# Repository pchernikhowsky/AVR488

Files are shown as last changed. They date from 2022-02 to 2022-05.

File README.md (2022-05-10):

# AVR488

A [Prologix](http://prologix.biz)<sup>TM</sup> compatible<sub><sup>(ish)</sup></sub> USB to [IEEE 488/GPIB/HP-IB](https://en.wikipedia.org/wiki/IEEE-488) controller interface based on the ATmega168/328 microcontroller.
<p align="center">
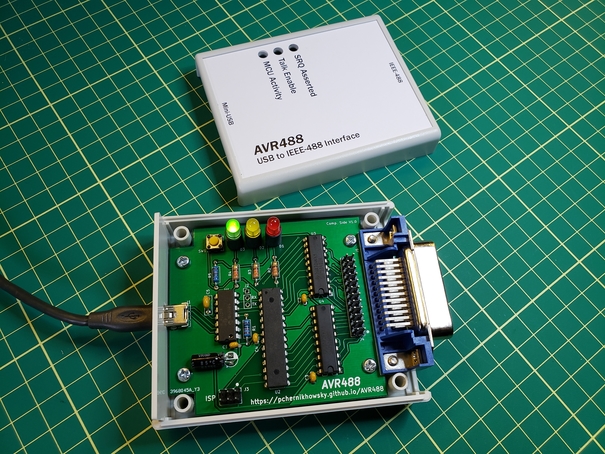
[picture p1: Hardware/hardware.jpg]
Completed hardware
  
</p>

## Description

I designed the AVR488 interface so that I could communicate with my various legacy Hewlett Packard / Agilent test instruments. There are numerous Arduino-based variations of USB/IEEE 488 interfaces out there already, but I prefer programming AVR devices down at the "bare metal" level using C code, so I came up with this version. Since it's necessary to construct a physical interface for the IEEE 488 connector anyway, it's easy enough to add an ATmega and driver ICs into that hardware design. Although it is intended to support a USB interface, a serial EIA-232 connection could also be implemented by deleting the USB interface IC and replacing it with an appropriate TTL to EIA-232 driver.

The embedded code size is approximately 13.5 KB and uses about 360 bytes of RAM, so there's more than enough free memory in an ATmega168 device. I have not included a bootloader (it avoids annoying startup delays and I prefer programming the ATmega directly using an ISP interface). If desired, there are many bootloaders available that could first be flashed to the device and then used to upload the AVR488 firmware.

**NOTE**: only controller mode (`++mode 1`) is implemented at this time, as I had no need for device mode. The latter is a possible future enhancement.

## Getting Started

### Dependencies

AVR488 supports both ATmega168 or ATmega328 devices (both the 10 and 20 MHz variants).

* Requires [MicroChip Studio 7 for AVR devices](https://www.microchip.com/en-us/tools-resources/develop/microchip-studio) for building the firmware.
* An ISP programmer (AVRISP MKII, AVR JTAG ICE, etc.) is needed to program the flash memory and set the fuses.

### Hardware Interfaces
* A USB 2.0 interface is provided by an [MCP2221A](https://www.microchip.com/en-us/product/MCP2221A) USB to TTL IC for connection to a host device (computer).
* The fully level-compliant IEEE 488 interface is implemented using the [SN75160](https://www.ti.com/lit/gpn/sn75als160) and [SN75161](https://www.ti.com/lit/gpn/sn75als161) driver ICs for connection to IEEE 488 devices.
* A direct serial EIA-232 interface could be implemented by using a [MAX232](https://www.ti.com/product/MAX232) (or equivalent) IC.

### Building and Installing the Firmware

1. Create a new project in MicroChip Studio and select the appropriate ATmega device.
2. Add the *.c and *.h files to the project.
3. Build the solution in MicroChip Studio.
4. Burn the code to your ATmega device.
5. Set the correct [fuses](Hardware/fuses.png):
   - Enable 8 MHz internal RC oscillator.
   - Disable divide by 8 clock divider (CKDIV8).
   - Enable brown-out detection (to provide protection against EEPROM corruption).
7. Connect the USB interface to a host computer and the IEEE 488 port to a device/instrument.
8. Upon first power-up, default settings will be stored in EEPROM. Settings can be changed and saved to EEPROM as required.
9. Enjoy!

When the AVR488 is first connected to a computer it will create a new USB serial port. The internal baud rate for the AVR488 serial port is fixed at 38400 bps (this can only be altered by changing a #define in the source code and reflashing). Thus, you MUST set the baud rate in your PC software (terminal program, etc.) to 38400 bps. A simple test to confirm that communications is fully working is to type the command "++help" (without the quotes). This should return a list available commands.

## Hardware Construction and Setup

You will need to construct your own hardware to support various ICs (ATmega168/328, MCP2221A, and SN75160/161) and the appropriate USB and IEEE 488 interface connectors. To make it easier, a full hardware design including [schematic](Hardware/AVR488-schematic.pdf), [bill of materials](Hardware/AVR488-BOM.csv), and PCB layout in KiCad format are provided. The PCB hardware and components have been selected to be hacker/hobbyist friendly; through-hole components are used exclusively. I ordered my PCBs from [JLCPCB](https://jlcpcb.com/), but feel free to use your preferred vendor. The PCB has been designed to fit inside a [Hammond 1593BB](https://www.hammfg.com/electronics/small-case/plastic/1593.pdf) plastic enclosure. A [dimensioned label](Hardware/AVR488-label.pdf) (including LED drilling dimensions) is also provided.

For simplicity, and to save pins, the internal 8 MHz RC oscillator in the ATmega168/328 is used as the clock source, so no external oscillator or crystal is required.

For diagnostic purposes, three LED outputs are provided:
* TE (Talk Enable): flashes when the TE signal to the IEEE 488 drivers goes high for driving data onto the bus.
* SRQ (Service Request): lights when the SRQ line is asserted, indicating that a device requires polling for status.
* STATUS: flashes during startup and then is continuously toggled when the watchdog timer is reset to indicate active processing (the toggling is around 130 kHz, so the LED is slightly dimmer than when fully on).

## Command List

The AVR488 command set is intended to be mostly compatible with the [Prologix GPIB-USB (HPIB-USB Controller)](http://prologix.biz/gpib-usb-controller.html). All commands are preceded by two plus signs (++). Any input not preceded by ++ is passed directly to the connected device(s). Input and commands from the host are buffered in a 254 byte buffer and then transmitted when either a CR (carriage return) or LF (line feed) character is received from the host. Not all Prologix commands have been implemented, and some do not operate exactly the same as the Prologix interface. Also, some extensions have been added for troubleshooting purposes (e.g., `debug` and `xdiag`) or for ease of use (e.g., `echo`).

Values enclosed in `[]` are optional. If a value is provided, the `[]` should not be included.

#### `++addr [n]`
Tell the interface which device to address (must be between 1 and 30). If no address is specified, the current device address will be displayed.

#### `++auto [n]`
Enable (1) or disable (0) automatic read-after-write when a "?" is included in the command sent to the device. If no value is provided, the current auto setting will be displayed.

#### `++clr`
Send a Select Device Clear (SDC) command to the currently addressed device.

#### `++debug [n]`
Enable simple (1), more verbose (2), or disable (0) debug logging messages. Convenient for troubleshooting problematic connections. If no value is provided, the current debug setting will be displayed.

#### `++default`
Emulates functionality of the AR488 command with the same name. The interface configuration is set with the following parameters:
* auto:	0
* eoi:	0 (disabled)
* eos:	0 (CR+LF)
* eot_enable:	0 (disabled)
* eot_char:	0
* address: 0
* read_tmo_ms:	1200
* echo: 0
* debug: 0

#### `++echo [n]`
Enable (1) or disable (0) echoing of characters received from USB port. Most IEEE 488 adapters require the sending application to enable local echo, but this is provided as an alternative. If no value is provided, the current echo setting will be displayed.

#### `++eoi [n]`
Enable (1) or disable (0) asserting the EOI line when the last byte is sent. If no value is provided, the current eoi setting will be displayed.

#### `++eos [n]`
Select the terminator characters to be appended to messages sent to the device: 0=CR+LF, 1=CR, 2=LF, 3=None. If no value is provided, the current eos setting will be displayed.

#### `++eot_char [n]`
ASCII code of character to be appended to messages received from the device (when EOI is used). If no value is provided, the current eot_char setting will be displayed.

#### `++eot_enable [n]`
Controls whether the eot_char is apprended to received messages. If no value is provided, the current eot_enable setting will be displayed.

#### `++help`
Print a list of commands and explanations.

#### `++ifc`
Issue an IEEE 488 interface clear by asserting the IFC line for 150 microseconds.

#### `++llo`
Disable front panel operation of the currently addressed device by sending the Local Lockout (LLO) command.

#### `++loc`
Enable front panel operation of the currently addressed device by sending the Go To Local (GTL) command.

#### `++mode [n]`
Compatibility-only command - we are always a controller. Any value provided is ignored and queries always return mode 1.

#### `++read`
Read from the currently addressed device until the eos terminating characters are received or a timeout occurs.

#### `++read eoi`
Read from the currently addressed device until either EOI is asserted, the eos terminating characters are received, or a timeout occurs.

#### `++read_tmo_ms [n]`
Sets the timeout value, in milliseconds, for the read and spoll commands. The default timeout is 1000 ms. If no value is provided, the current read_tmo_ms setting will be displayed.

#### `++rst`
Performs a power-on reset of the controller interface by forcing a watchdog timer timeout. Takes approximately 2 seconds.

#### `++savecfg 1`
Saves the current settings to EEPROM. Settings saved include: addr, eot_char, eot_enable, eos, eoi, auto, debug, and echo. Settings are **not** saved automatically when they are changed (to prevent unnecessary wear on the EEPROM). The value "1" must be included or the command is ignored.

#### `++spoll [n]`
Read the device status byte by issuing a Serial Poll command. If no address is specified the serial poll request will be sent to the currently addressed device.

#### `++srq`
Query the status of SRQ line. Returns 0 if the line is not asserted and 1 if asserted.

#### `++trg [n]`
Issue a Group Execute Trigger (GET) to a device. If no address is specified the trigger will be sent to the currently addressed device.

#### `++ver`
Query the current AVR488 firmware version.

#### `++xdiag`
Show the current state of the ATmega IO pins (for troubleshooting purposes).

## Version History

* 1.1
    * Firmware changes to improve AR488 and Prologix compatibility.
* 1.0
    * Initial Release

## License

This project is licensed under the GPL-3.0 License. See the [LICENSE](LICENSE) file for details.

## Acknowledgments

Inspiration, code snippets, libraries.
* [AR488](https://github.com/Twilight-Logic/AR488)
* [atmega-gpib](https://github.com/pepaslabs/atmega-gpib)
* [gpibusb-firmware](https://github.com/Galvant/gpibusb-firmware)
* [Peter Fleury's interrupt-driven UART library](http://www.peterfleury.epizy.com/doxygen/avr-gcc-libraries/group__pfleury__uart.html)

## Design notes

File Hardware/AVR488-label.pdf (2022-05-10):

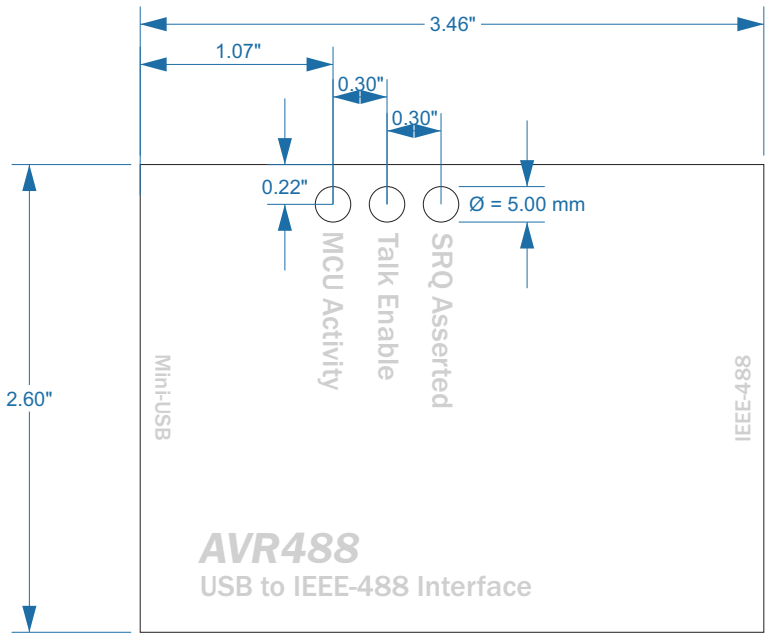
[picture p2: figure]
AVR488; USB to IEEE-488 Interface MCU Activity Talk Enable; SRQ Asserted; IEEE-488; Mini-USB

## AVR488

USB to IEEE-488 Interface MCU Activity Talk Enable

SRQ Asserted

IEEE-488

Mini-USB

Dimensioned for Hammond 1593BB enclosure http://www.hammondmfg.com/pdf/1593BB.pdf

Ensure “Actual size” is selected in the Print dialog.

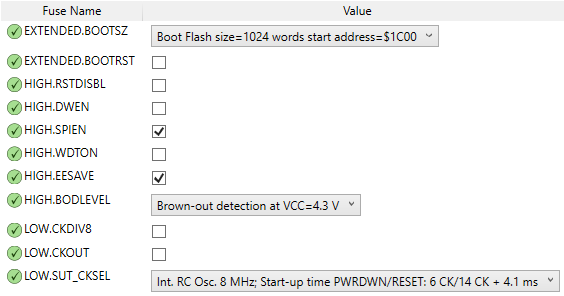
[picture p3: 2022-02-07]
Hardware/fuses.png

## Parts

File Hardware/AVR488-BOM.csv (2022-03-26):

Qty | Reference(s) | Value | Manufacturer | Digi-Key Part Number | PartNo
4 | C1, C2, C3, C4 | 0.1uF | KEMET | 399-4264-ND | C320C104K5R5TA
1 | C5 | 0.47 uF | KEMET | 399-14020-ND | C330C474M5R5TA
1 | C6 | 1uF | Nichicon | 493-12567-1-ND | UVK1H010MDD1TD
1 | D1 | LED(R) | Lite-On | 160-1705-ND | LTL-307E
1 | D2 | LED(Y) | Lite-On | 160-1703-ND | LTL-307Y
1 | D3 | LED(G) | Lite-On | 160-1706-ND | LTL-307G
1 | J1 | Mini USB | TE Connectivity AMP Connectors | A135698-ND | 2172034-1
1 | J2 | SERIAL | Amphenol ICC (FCI) | 10129378-903001BLF-ND | 10129378-903001BLF
1 | J3 | ISP | Amphenol ICC (FCI) | 10129381-906001BLF-ND | 10129381-906001BLF
1 | J4 | HEADER | Amphenol ICC (FCI) | 10129381-924001BLF-ND | 10129381-924001BLF
1 | J5 | IEEE488 | NorComp Inc. | 1024RMA-ND | 112-024-113R001
2 | R1, R5 | 10k | Stackpole Electronics Inc | CF18JT10K0TR-ND | CF18JT10K0
3 | R2, R3, R4 | 330R | Stackpole Electronics Inc | CF18JT330RTR-ND | CF18JT330R
1 | SW1 | RESET | Omron | SW797CT-ND | B3F-6002
1 | U1 | MCP2221AxP | Microchip Technology | MCP2221A-I/P-ND | MCP2221A-I/P
1 | U2 | ATmega168-20P | Microchip Technology | ATMEGA168V-10PU-ND | ATMEGA168V-10PU
1 | U3 | SN75161BN | Texas Instruments | 296-6847-5-ND | SN75161BN
1 | U4 | SN75160BN | Texas Instruments | 296-6845-5-ND | SN75160BN
3 |  | LED Standoffs | Bivar Inc. | ELM3-440-ND | ELM 3-440
2 |  | #4-40 connector mounting screws | Keystone | 36-9900-ND | 9900
1 |  | Enclosure | Hammond Manufacturing | HM1376-ND | 1593BBGY

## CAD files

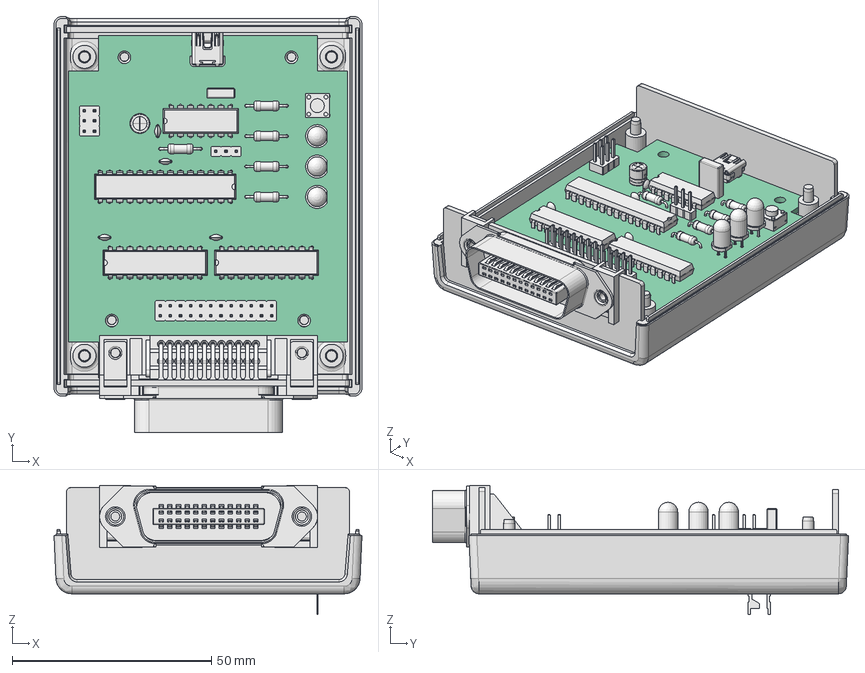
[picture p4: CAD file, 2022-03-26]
Hardware/AVR488.FCStd
77.3 x 104.4 x 32.4 mm
1593BB BOTTOM
1593BB End Panel
1593BB End Panel001
SC549 (screw #4X 3_4' OH)
SC549 (screw #4X 3_4' OH)001
SC549 (screw #4X 3_4' OH)002
SC549 (screw #4X 3_4' OH)003
Pcb_4d56
U1_DIP-14_W7.62mm_07c7e3d0463e
R3_R_Axial_DIN0207_L63mm_D25mm_P1016mm_Horizontal_f71aacabab9c x 5
U4_DIP-20_W7.62mm_8dba236a9cba x 2
D2_LED_D5.0mm_e4c8e7621137 x 3
J4_PinHeader_2x12_P254mm_Vertical_2a5a55a7fb98
J3_PinHeader_2x03_P254mm_Vertical_44d44c696a08
U2_DIP-28_W7.62mm_c51a3d9690d5
C4_C_Disc_D30mm_W16mm_P250mm_9aaeda4f0cdd x 4
J2_PinHeader_1x03_P254mm_Vertical_70d33e2d6c7e
C5_C_Rect_L70mm_W25mm_P500mm_720b4647ee08
C6_CP_Radial_D50mm_P250mm_bbad7ffecfd3
J5_112-024-113R001_fb36ff756c3c
SW1_B3F_602[]_423e57562a1d
J1_C-2172034-1_a05471a474e2

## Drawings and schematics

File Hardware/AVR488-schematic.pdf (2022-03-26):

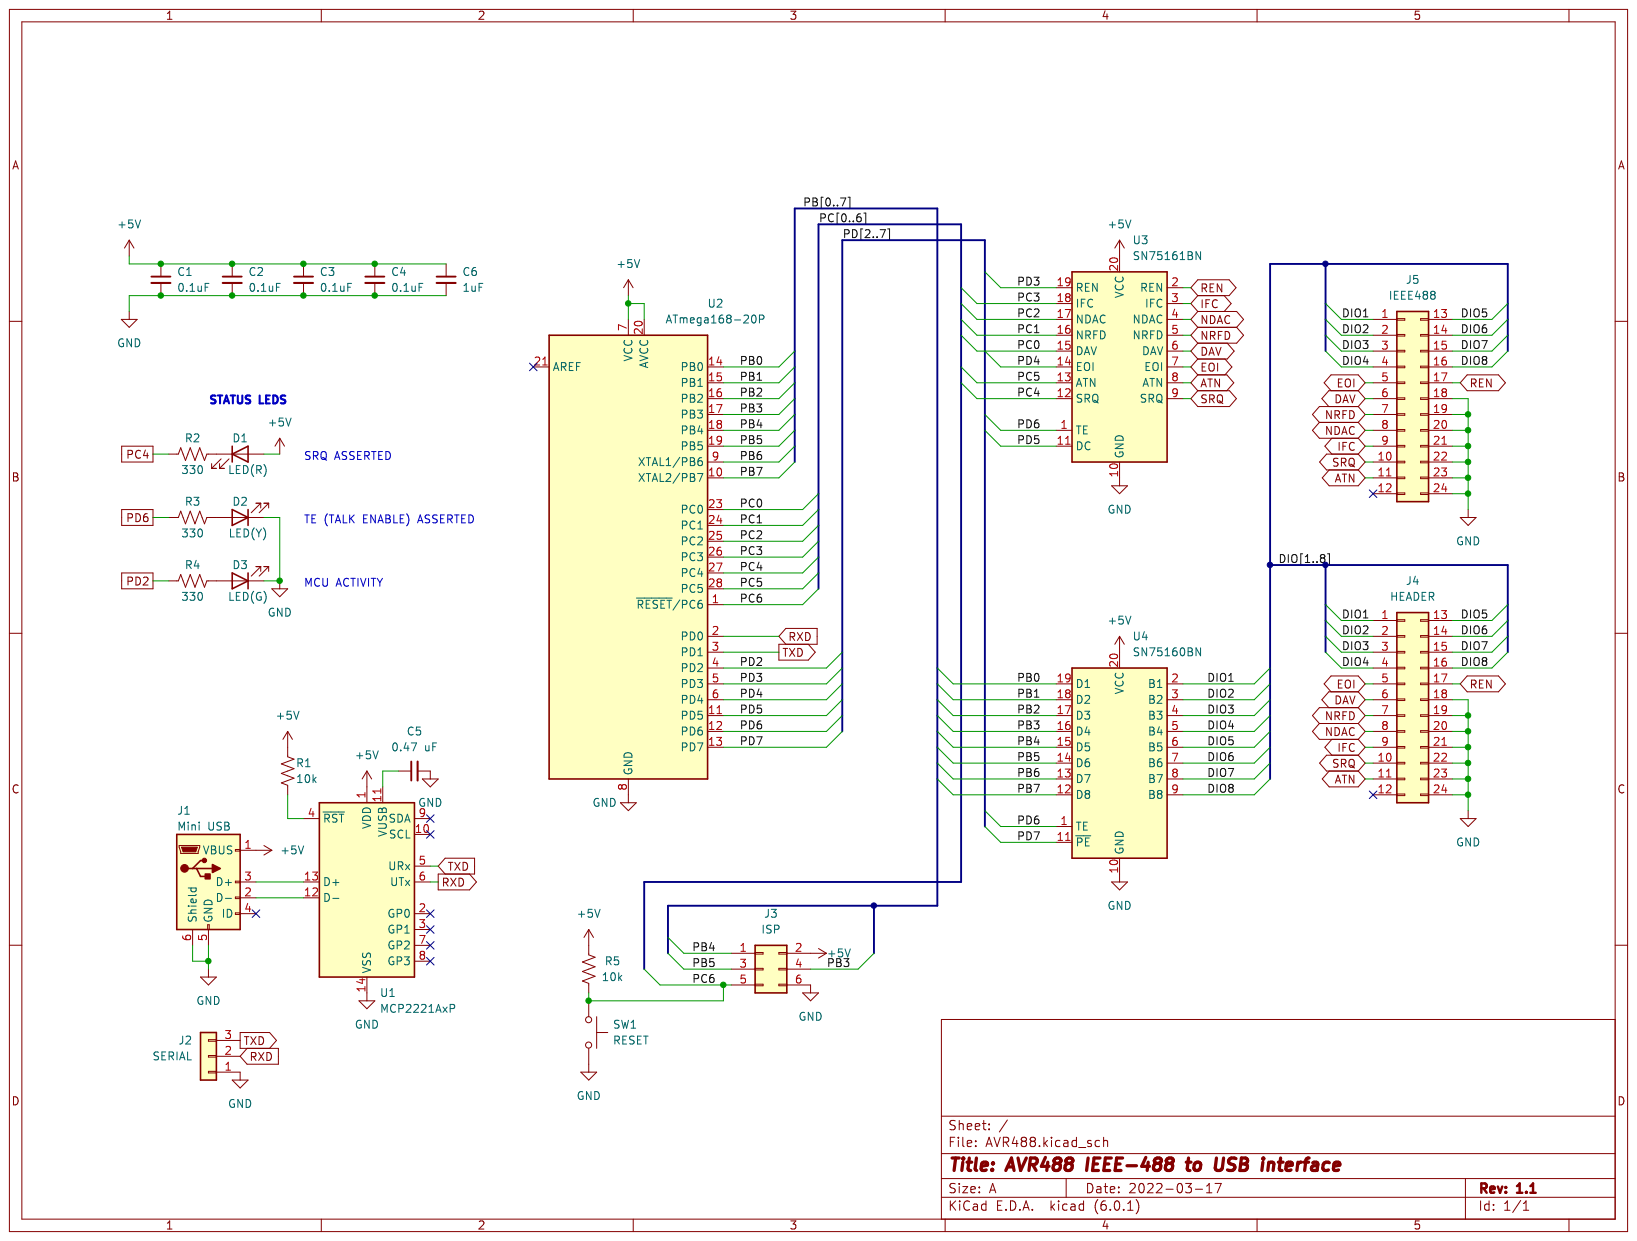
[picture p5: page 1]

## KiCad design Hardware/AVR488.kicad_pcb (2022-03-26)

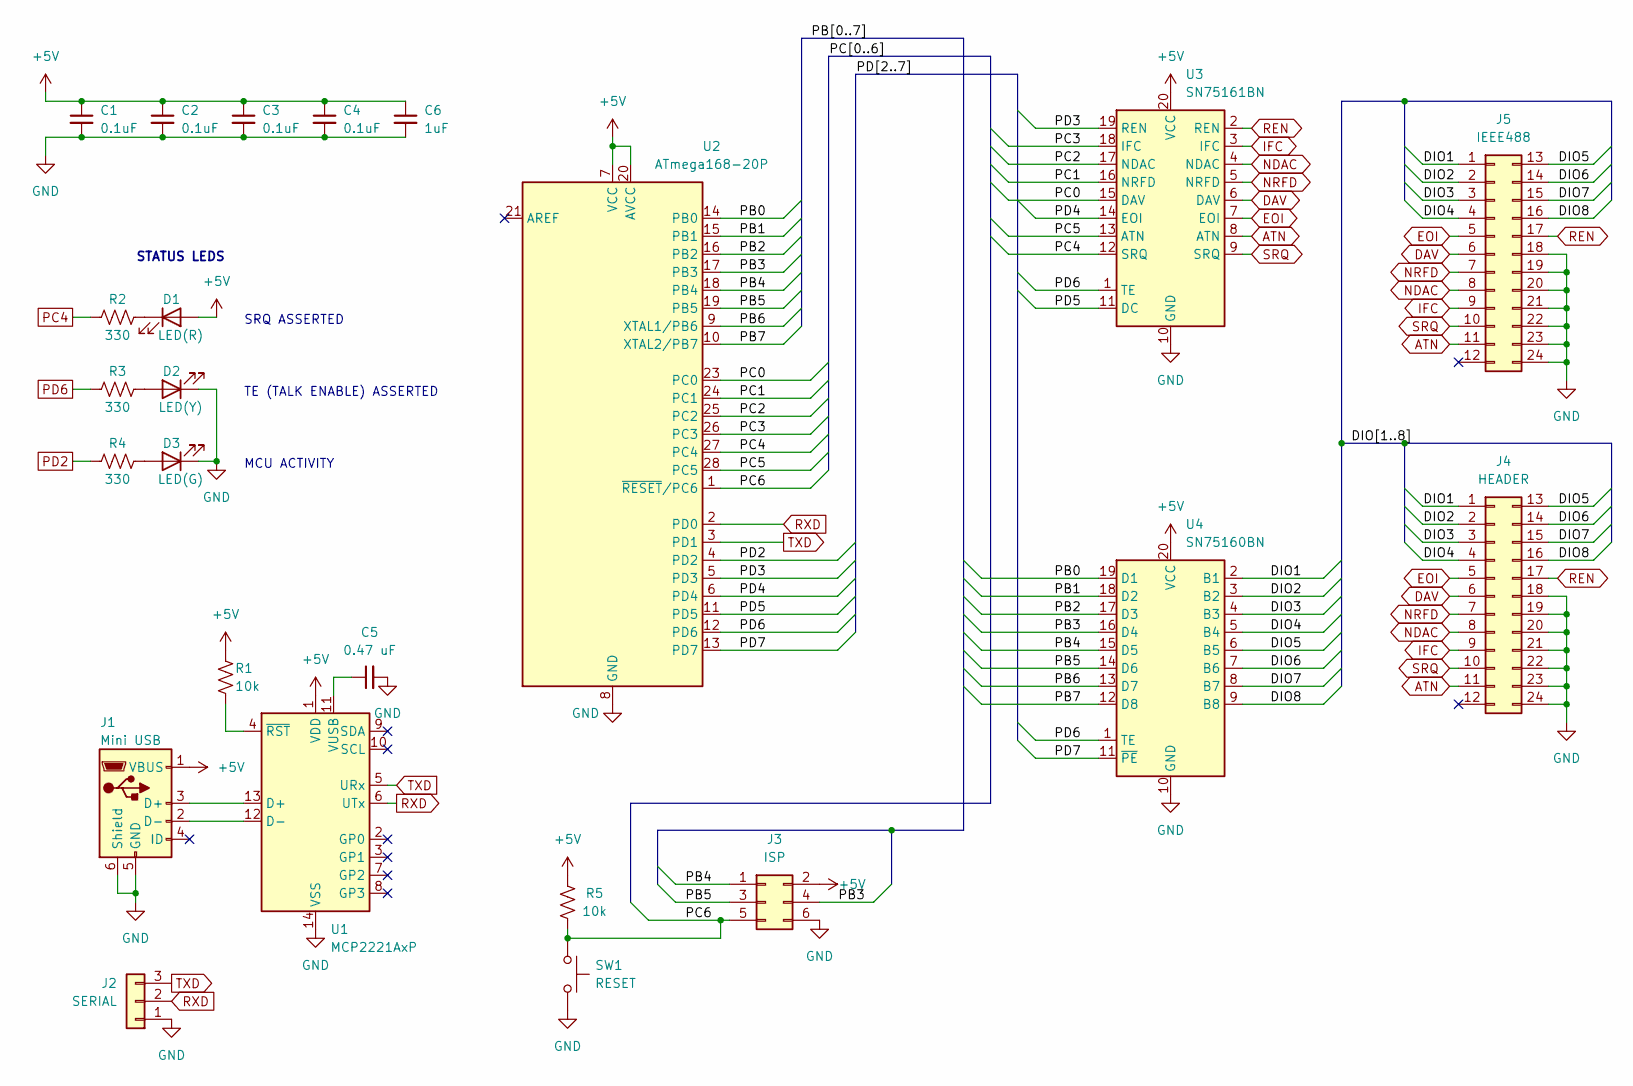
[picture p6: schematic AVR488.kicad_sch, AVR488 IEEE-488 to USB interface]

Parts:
C1, C2, C3, C4: 0.1uF; C_Disc_D3.0mm_W1.6mm_P2.50mm; PartNo C320C104K5R5TA
C5: 0.47 uF; C_Rect_L7.0mm_W2.5mm_P5.00mm; PartNo C330C474M5R5TA
C6: 1uF; CP_Radial_D5.0mm_P2.50mm; PartNo UVK1H010MDD1TD
D1: LED(R); LED_D5.0mm; PartNo LTL-307E
D2: LED(Y); LED_D5.0mm; PartNo LTL-307Y
D3: LED(G); LED_D5.0mm; PartNo LTL-307G
J1: Mini USB; 2172034-1; PartNo 2172034-1
J2: SERIAL; PinHeader_1x03_P2.54mm_Vertical
J3: ISP; PinHeader_2x03_P2.54mm_Vertical
J4: HEADER; PinHeader_2x12_P2.54mm_Vertical
J5: IEEE488; 112-024-113R001; PartNo 112-024-113R001
R1, R5: 10k; R_Axial_DIN0207_L6.3mm_D2.5mm_P10.16mm_Horizontal; PartNo CF18JT10K0
R2, R3, R4: 330; R_Axial_DIN0207_L6.3mm_D2.5mm_P10.16mm_Horizontal; PartNo CF18JT330R
SW1: RESET; B3F-6002; PartNo B3F-6002
U1: MCP2221AxP; DIP-14_W7.62mm; PartNo MCP2221A-I/P
U2: ATmega168-20P; DIP-28_W7.62mm; PartNo ATMEGA168A-PU
U3: SN75161BN; DIP-20_W7.62mm; PartNo SN75161BN
U4: SN75160BN; DIP-20_W7.62mm; PartNo SN75160BN

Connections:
+5V: C1.1, C2.1, C3.1, C4.1, C6.1, D1.2 (A), J1.1 (VBUS), J3.2, R1.1, R5.2, U1.1 (VDD), U2.7 (VCC), U2.20 (AVCC), U3.20 (VCC), U4.20 (VCC)
/DIO1: J4.1, J5.1, U4.2 (B1)
/DIO2: J4.2, J5.2, U4.3 (B2)
/DIO3: J4.3, J5.3, U4.4 (B3)
/DIO4: J4.4, J5.4, U4.5 (B4)
/DIO5: J4.13, J5.13, U4.6 (B5)
/DIO6: J4.14, J5.14, U4.7 (B6)
/DIO7: J4.15, J5.15, U4.8 (B7)
/DIO8: J4.16, J5.16, U4.9 (B8)
/PB0: U2.14 (PB0), U4.19 (D1)
/PB1: U2.15 (PB1), U4.18 (D2)
/PB2: U2.16 (PB2), U4.17 (D3)
/PB3: J3.4, U2.17 (PB3), U4.16 (D4)
/PB4: J3.1, U2.18 (PB4), U4.15 (D5)
/PB5: J3.3, U2.19 (PB5), U4.14 (D6)
/PB6: U2.9 (XTAL1/PB6), U4.13 (D7)
/PB7: U2.10 (XTAL2/PB7), U4.12 (D8)
/PC0: U2.23 (PC0), U3.15 (DAV)
/PC1: U2.24 (PC1), U3.16 (NRFD)
/PC2: U2.25 (PC2), U3.17 (NDAC)
/PC3: U2.26 (PC3), U3.18 (IFC)
/PC5: U2.28 (PC5), U3.13 (ATN)
/PC6: J3.5, R5.1, SW1.1, U2.1 (~RESET/PC6)
/PD3: U2.5 (PD3), U3.19 (REN)
/PD4: U2.6 (PD4), U3.14 (EOI)
/PD5: U2.11 (PD5), U3.11 (DC)
/PD7: U2.13 (PD7), U4.11 (~PE)
ATN: J4.11, J5.11, U3.8 (ATN)
DAV: J4.6, J5.6, U3.6 (DAV)
EOI: J4.5, J5.5, U3.7 (EOI)
GND: C1.2, C2.2, C3.2, C4.2, C5.2, C6.2, D2.1 (K), D3.1 (K), J1.5 (GND), J1.6 (Shield), J2.1, J3.6, J4.18, J4.19, J4.20, J4.21, J4.22, J4.23, J4.24, J5.18, J5.19, J5.20, J5.21, J5.22, J5.23, J5.24, SW1.2, U1.14 (VSS), U2.8 (GND), U2.22 (GND), U3.10 (GND), U4.10 (GND)
IFC: J4.9, J5.9, U3.3 (IFC)
NDAC: J4.8, J5.8, U3.4 (NDAC)
NRFD: J4.7, J5.7, U3.5 (NRFD)
unnamed: C5.1, U1.11 (VUSB)
unnamed: D1.1 (K), R2.2
unnamed: D2.2 (A), R3.2
unnamed: D3.2 (A), R4.2
unnamed: J1.2 (D-), U1.12 (D-)
unnamed: J1.3 (D+), U1.13 (D+)
unnamed: R1.2, U1.4 (~RST)
PC4: R2.1, U2.27 (PC4), U3.12 (SRQ)
PD2: R4.1, U2.4 (PD2)
PD6: R3.1, U2.12 (PD6), U3.1 (TE), U4.1 (TE)
REN: J4.17, J5.17, U3.2 (REN)
RXD: J2.2, U1.6 (UTx), U2.2 (PD0)
SRQ: J4.10, J5.10, U3.9 (SRQ)
TXD: J2.3, U1.5 (URx), U2.3 (PD1)

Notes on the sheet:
SRQ ASSERTED
STATUS LEDS
TE (TALK ENABLE) ASSERTED
MCU ACTIVITY

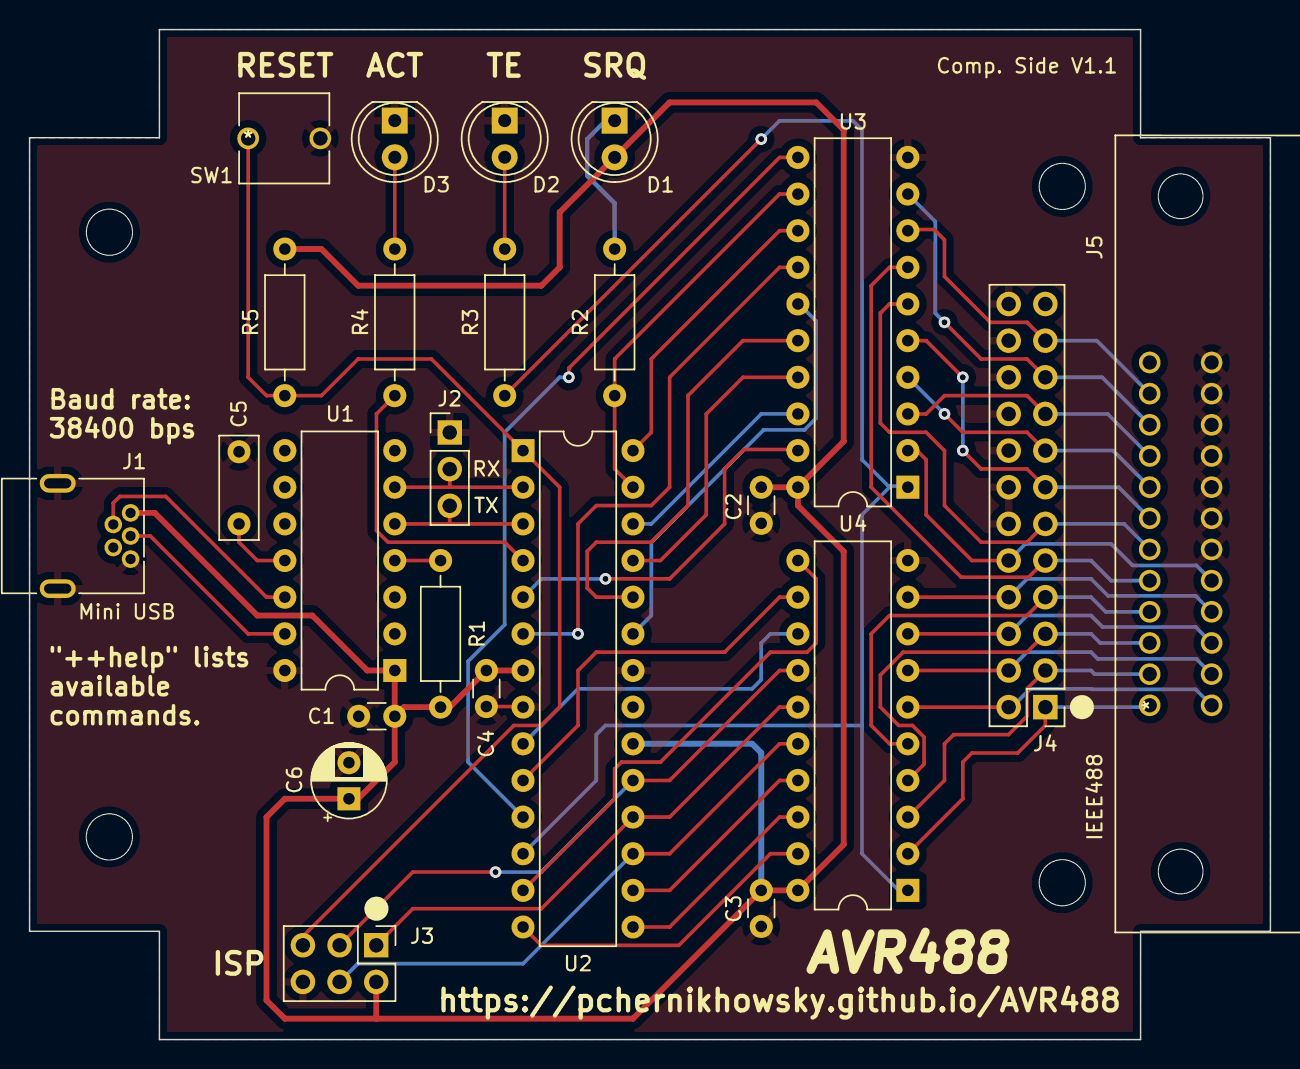
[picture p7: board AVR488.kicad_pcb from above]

Board: 2 copper layers, 86.0 x 70.0 mm, 28 parts (0 on the bottom side), 48 nets.

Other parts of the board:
REF1, REF2, REF3, REF4: MountingHole_3.2mm_M3

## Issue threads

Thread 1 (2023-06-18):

USB to IEEE-488 interface work with EZGPIB and GPIB configurator

llrr-new, 2023-06-18:
Hello Pchernikhowsky

I recreated your wonderful project. The USB to IEEE-488 interface works. There is communication and the ++ commands are executed.

I use the program EZGPIB to control measuring instruments. With this program you can easily control multiple measuring equipment via the GPIB interface.
The program EZGPIB is written for the Prologix interface and when starting this program, all available PC ports are searched for a GPIB interface.
After this the ++ver command is sent and the program expects the message back with the text “prologix GPIB-USB interface.
If this text does not appear, no connection will be made and EZGPIB will not be usable.
A similar problem occurs with the program GPIB configurator.
I have copied several types of GPIB-USB DIY designs and the designers have all ensured that the tools EZGPIB and GPIB configurator were usable.

Is it possible that this can also be built into your program?

Yours sincerely,

Loek

pchernikhowsky, 2023-06-18:
Good day - great to hear that someone has interest in this!

I specifically tested for compatibility with the Prologix GPIB Configurator program (see image below), so I know the AVR488 interface can work with it. I suspect that all you need to do is to first connect using a terminal program to the correct serial port and issue the "++default" command. This will reset the AVR488 internal communications parameters to make it look exactly like the popular AR488 interface. The GPIB Configurator program should find it then. Optionally you can then use the "++savecfg 1" command to save these settings to eeprom to ensure that it also starts up in AR488 compatibly mode.

I cant remember if I test for compatibility with the EZGPIB program - give me a little bit and I'll look into this.

Cheers,
Paul

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

pchernikhowsky, 2023-06-19:
I've confirmed that the AVR488 does not work with EZGPIB - and there's no easy solution. The problem is that EZGPIB is looking for RTS to be asserted on the serial port connected to the AVR488 (see image below). Unfortunately, the MCP2221A used in this design for the USB to serial interface does not support RTS/CTS signaling (very annoying - thanks for nothing, Microchip).

As such, there are only two solutions:

1. Redesign the hardware to use an alternative USB to serial interface IC. There no DIP IC alternatives available, so this would mean switching to a surface mount IC (which I have tried to avoid to make the hardware easy to assemble). If I were to go this route (surface mount ICs) it would likely make more sense to just use an ATmega (e.g., ATmega32U4) with a built-in USB interface to avoid the interface issue entirely. But these are very hacker unfriendly for soldering.
2. Modify the EZGPIB software to ignore the state of the serial port RTS line. The author of the software would have to make this change.

As such, I'm closing this out this issue as a "can't fix" for EZGPIB and "tested - not an issue" for GPIB Configurator.

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

Closed 2023-06-19.

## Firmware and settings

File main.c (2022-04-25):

/*
 * AVR488
 *
 * Created: 28-Dec-2021 7:14:34 PM
 *
 * Prologix compatible(ish) GPIB to USB Adapter based on the Atmel/Microchip ATmega168/328 devices
 *
 * Inspired by code from
 * (https://github.com/Galvant/gpibusb-firmware) and AR488 (https://github.com/Twilight-Logic/AR488)
 *
 * This program is distributed in the hope that it will be useful,
 * but WITHOUT ANY WARRANTY; without even the implied warranty of
 * MERCHANTABILITY or FITNESS FOR A PARTICULAR PURPOSE.
 */

#define F_CPU 8000000UL	// internal RC oscillator frequency = 8 MHz
#define BAUD 38400 // USART baud rate
#define MY_VERSION "1.1" // firmware version display with the help screen
#define PROLOGIX_VERSION "AVR488 GPIB-USB Controller Version 6.00" // firmware version displayed by the ++ver command (for Prologix compatibility)

#include <avr/io.h>
#include <avr/pgmspace.h>
#include <avr/wdt.h>
#include <avr/eeprom.h>
#include <avr/interrupt.h>
#include <util/delay.h>
#include <util/setbaud.h>
#include <string.h>
#include <stdio.h>
#include <stdlib.h>
#include <stdbool.h>
#include <string.h>
#include <ctype.h>
#include "main.h"
#include "uart.h"
#include "pinio.h"

uint8_t mcusr __attribute__((section(".noinit"))); // save the MCUSR reset cause

FILE usart_str = FDEV_SETUP_STREAM(uart_putchar, NULL, _FDEV_SETUP_WRITE); // Use streams for character output to usart only
char cmd_buf[5], buf[BUFSIZE];

bool eoiUse; // whether we are using EOI to signal end of message from instrument
bool eot_enable; // whether to append eot_char after EOI
char debug; // debug level for read&write error messages
char eot_char; // end of transmission character added after EOI
char eos_code; // end of transmission code to end a transmission to the instrument
char eos_string[3]; // characters to end a transmission to the instrument

// Variables timeout monitoring during transmit/receive
unsigned int timeout = 1000; // used for send/receive timeout monitoring - default timeout is 1000 milliseconds
volatile unsigned int ticks = 0; // incremented in ISR (so use volatile declaration)


/***********************************************************************************************************
*
* Start of helper subroutines
*
************************************************************************************************************/

/*
 * TIMER1 interrupt handler
 */
ISR(TIMER1_COMPB_vect)
{
	++ticks;	// increment tick counter every millisecond
}


/*
* Reset the watchdog timer and toggle the status LED
*/
void _wdt_reset(void)
{
	wdt_reset();
	PIND = 1<<(LED_STATUS & 0x7f); // strip the high bit from the define
}


/*
 * Puts all the GPIB pins into their correct initial states.
 */
void prep_gpib_pins()
{
	output_low(TE); // Disable Talk Enable for data and handshake lines
	output_high(PE); // Enable Pullups for bus transceivers
	output_low(DC); // Allows transmit on ATN/REN/IFC and listen on SRQ

	// tri-state data pins
	DDRB = 0;	 // all pins input
	PORTB = 0xff; // enable pullups

	DEASSERT(ATN);
	FLOAT(EOI);
	FLOAT(DAV);
	ASSERT(NRFD);
	ASSERT(NDAC);
	DEASSERT(IFC);
	FLOAT(SRQ);
	ASSERT(REN);
}


/*
 * Send a multibyte GPIB data string (command or data).
 */
char _gpib_write(char *bytes, int length, bool attention)
{
    /*
    * Write a string of bytes to the bus
    * bytes: array containing characters to be written
    * length: number of bytes to write, 0 if not known.
    * attention: 1 if this is a GPIB command, 0 for data
	*
	* Returns true if there was an error
    */
	char a; // Storage variable for the current character
	int i; // Loop counter variable

	if(attention) // If byte is a GPIB bus command
		ASSERT(ATN); // Assert the ATN line, informing all that this is a command byte

	if(length==0) // If the length was unknown
		length = strlen(bytes); // Calculate the number of bytes to be sent

	output_high(TE); // Enable talking
	DEASSERT(EOI);
	DEASSERT(DAV);
	FLOAT(NRFD); // Let talkers control NRFD and NDAC
	FLOAT(NDAC);

	if (debug > 1)
		printf_P(PSTR("NDAC:%u / NRFD:%u\n\r"), input(NDAC), input(NRFD));

	for(i = 0;i < length;i++) //Loop through each character, write to bus
	{
		a = bytes[i]; // Character to send

		// Wait for listeners to be ready for data (NRFD should be high and NDAC low)
		ticks = 0;
		while((!input(NRFD) || input(NDAC)) && (ticks <= timeout))
		{
		    _wdt_reset();
			if(ticks >= timeout)
			{
			    if (debug > 1)
				    printf_P(PSTR("Timeout: Waiting for NRFD to go high and NDAC to go low while writing\n\r"));
			    prep_gpib_pins();
				return 1;
			}
		}

		// Enable port B for output and put the byte on the data lines using negative logic
		if (debug > 1)
		{
			if (attention)
				printf_P(PSTR("Writing command byte: 0x%02x\n\r"), a);
			else
				printf_P(PSTR("Writing data byte: %c 0x%02x\n\r"), isprint(a)?a:' ', a);
		}
		DDRB = 0xff;
		PORTB = ~a;

		if((i==length-1) && eoiUse && !attention)
		{
			ASSERT(EOI); // If last byte in string assert EOI
		    if (debug > 1)
			    printf_P(PSTR("Asserting EOI\n\r"));
		}
		_delay_us(150); // delay to allow lines to settle
		ASSERT(DAV); // Inform listeners that the data is ready to be read
		_delay_us(150); // delay to allow lines to settle

		// Wait for NDAC to go high, all listeners have accepted the byte
		ticks = 0;
		while(!(input(NDAC)) && (ticks <= timeout))
		{
		    _wdt_reset();
			if(ticks >= timeout)
			{
			    if (debug > 1)
			        printf_P(PSTR("Timeout: Waiting for NDAC to go high while writing\n\r"));
			    prep_gpib_pins();
				return 1;
			}
		}

		DEASSERT(DAV); // Byte has been accepted by all, indicate the byte is no longer valid

	} // Finished outputting all bytes to listeners

	DDRB = 0; // Set Port B back to all inputs (pull-ups are still active)
	output_low(TE); // Disable talking on data lines

	if(attention) // If byte was a GPIB command byte release ATN line
		DEASSERT(ATN);

	FLOAT(DAV);
	FLOAT(EOI);
	DEASSERT(NDAC);
	DEASSERT(NRFD);

	return 0;
}


/*
 * Send a multibyte GPIB command (ATN line asserted).
 */
char gpib_cmd(char *bytes, int length)
{
	if (debug > 1)
		printf_P(PSTR("gpib_cmd(): %d bytes\n\r"), length);

    // Write a GPIB CMD byte to the bus
	return _gpib_write(bytes, length, 1);
}


/*
 * Make ourselves the bus controller.
 */
char gpib_controller_assign(void)
{
	ASSERT(IFC); // Assert interface clear. Resets bus and makes it controller in charge.
	_wdt_reset();
	_delay_us(150);
	FLOAT(IFC); // Finishing clearing interface

	ASSERT(REN); // Put all connected devices into "remote" mode
	cmd_buf[0] = CMD_DCL;
	return gpib_cmd(cmd_buf, 1); // Send GPIB DCL command, clear all devices on bus
}


/*
 * Send a multibyte GPIB data string (ATN line not asserted).
 */
char gpib_write(char *bytes, int length)
{
	if (debug > 1)
		printf_P(PSTR("gpib_write(): \"%s\"\n\r"),bytes);

    // Write a GPIB data string to the bus
	return _gpib_write(bytes, length, 0);
}


/*
 * Receive a single byte from the GPIB bus.
 */
char gpib_receive(char *byte)
{
	char a = 0; // Storage for received character
	char eoiStatus; // Returns 0x00 or 0x01 depending on status of EOI line or 0xff for error

	// Let the talker control the data valid line
	FLOAT(DAV);

	// Raise NRFD, telling the talker we are ready for the byte
	DEASSERT(NRFD);

	// Assert NDAC informing the talker we have not accepted the byte yet
	ASSERT(NDAC);

	// Wait for DAV to go low (talker informing us the byte is ready)
    ticks = 0;
	while (input(DAV) && (ticks <= timeout))
	{
	    _wdt_reset();
		if (ticks >= timeout)
		{
		    if (debug > 1)
			    printf_P(PSTR("Timeout: Waiting for DAV to go low while reading\n\r"));
		    prep_gpib_pins();
			return 0xff;
		}
	}

	// Assert NRFD, informing talker to not change the data lines
	ASSERT(NRFD);

	// Read port B, where the data lines are connected
	a = ~PINB; // Flip all bits since GPIB uses negative logic.
	eoiStatus = input(EOI);
	_delay_us(150);

	if (debug > 1)
		printf_P(PSTR("Read byte: %c 0x%02x\n\r"), isprint(a)?a:' ', a);

	// Deassert NDAC, informing talker that we have accepted the byte
	FLOAT(NDAC);
	_delay_us(150);

	// Wait for DAV to go high (talker knows that we have read the byte)
    ticks = 0;
	while(!(input(DAV)) && (ticks<=timeout) )
	{
	    _wdt_reset();
		if(ticks >= timeout)
		{
		    if (debug > 1)
			    printf_P(PSTR("Timeout: Waiting for DAV to go high while reading\n\r"));
		    prep_gpib_pins();
			return 0xff;
		}
	}

	// Prep for next byte, we have not accepted anything
	ASSERT(NDAC);

	if (debug > 1)
		printf_P(PSTR("EOI: %x\n\r"), (eoiStatus>0)?0:1); // invert EOI (negative logic)

	*byte = a;

	return eoiStatus;
}


/*
 * Receive a multiple bytes from the GPIB bus until either EOI or timeout. Returns non-zero if an error occurs.
 */
char gpib_read(bool read_until_eoi, uint8_t partnerAddress)
{
	char readCharacter, eoiStatus;
	char errorFound = 0;
	bool reading_done = false;

	if (debug > 1)
		printf_P(PSTR("gpib_read start - read_until_eoi=%d\n\r"), read_until_eoi);

	cmd_buf[0] = CMD_UNT;
	cmd_buf[1] = CMD_UNL;
	cmd_buf[2] = partnerAddress + 0x40;
	errorFound = gpib_cmd(cmd_buf, 3);
	if (errorFound)
		return 1;

	if (debug > 1)
		printf_P(PSTR("gpib_read loop start\n\r"));

	if (read_until_eoi == 1) // loop until we get an EOI indication
	{
		do
		{
			eoiStatus = gpib_receive(&readCharacter); // eoiStatus is line level
			_wdt_reset();
			if (!debug)
				putchar(readCharacter);
			if(eoiStatus == 0xff)
			{
				errorFound = 1;
				break;
			}
		} while (eoiStatus);
		if ( eot_enable)
			putchar(eot_char);
	}
	else // loop until we get an EOS character
	{
		do
		{
			eoiStatus = gpib_receive(&readCharacter);
			_wdt_reset();
			if (!debug)
				putchar(readCharacter);
			if (eoiStatus==0xff)
			{
				errorFound = 1;
				break;
			}
			if (eos_code != 3)
			{
			    if (readCharacter == eos_string[0]) // Check for EOM chars
			        reading_done = true;
			    if (readCharacter == eos_string[1])
		            reading_done = true;
			}
		} while (reading_done == false);
	}

	// Command all talkers and listeners to stop
	cmd_buf[0] = CMD_UNT;
	cmd_buf[1] = CMD_UNL;
	errorFound = gpib_cmd(cmd_buf, 2);

	if (debug > 1)
		printf_P(PSTR("gpib_read end (error=%d\n\r"), errorFound);

	return errorFound;
}


/*
* Address the currently specified GPIB address (as set by the ++addr cmd) to listen
*/
char addressTarget(int address)
{
    cmd_buf[0] = CMD_UNT; // everyone stop talking
    cmd_buf[1] = CMD_UNL; // everyone stop listening
    cmd_buf[2] = address + 0x20; // tell addressed device to listen
    return gpib_cmd(cmd_buf, 3);
}


/*
* Fetch (and invert - due to negative logic) the state of the SRQ bus line
*/
bool srq_state(void)
{
    return !input(SRQ);	// invert due to negative logic
}


/*
* Fetch the instrument status byte using a serial poll command
*/
void serial_poll(int address)
{
    char error = 0;
    char status_byte;
	char buffer [10];

    cmd_buf[0] = CMD_SPE; // enable serial poll
	cmd_buf[1] = address + 0x40;
    error = gpib_cmd(cmd_buf, 2);
    if ( gpib_receive(&status_byte) == 0xff)
		error = 1;
    cmd_buf[0] = CMD_SPD; // disable serial poll
	error = error || gpib_cmd(cmd_buf, 1);
	if (!error)
	{
		utoa(status_byte,buffer,2);
	    printf_P(PSTR("%s\n\r"), buffer);
	}
	else
	    printf_P(PSTR("ERROR\n\r"));
}


/*
* Start TIMER1 to generate periodic interrupts (for use in data transmission timeout monitoring)
*/
void init_timer(void)
{
	TCCR1B = 0x00; // stop timer
	TCCR1A = 0x00; // OC1x output compare and PWM not used
	OCR1A = 1000; // count to 1000 - gives a 1.0 ms periodic interrupt
	TCCR1B = 1<<WGM12 | 1<<CS11; // start timer with divide by 8 prescaler and clear count on compare match
	TIMSK1 |= 1<<OCIE1B; // enable the timer interrupt to free run
}


/*
* Read out and reset mcusr early during startup. Also disable WDT if it was left running after reset.
*/
void handle_mcusr(void)
__attribute__((section(".init3")))
__attribute__((naked));
void handle_mcusr(void)
{
	mcusr = MCUSR;
	MCUSR = 0;
	wdt_disable();
}


/*
* Populate the GPIB end of string terminators
*/
void set_eos_string(uint8_t code)
{
    switch (code)
    {
	    case 0:
			eos_code = 0;
			eos_string[0] = '\r';
			eos_string[1] = '\n';
			eos_string[2] = 0x00;
		    break;
	    case 1:
			eos_code = 1;
			eos_string[0] = '\r';
			eos_string[1] = 0x00;
			break;
		case 2:
			eos_code = 2;
			eos_string[0] = '\n';
			eos_string[1] = 0x00;
			break;
		default:
			eos_code = 3;
			eos_string[0] = 0x00;
			break;
    }
}


/*
* Show all valid commands
*/
void print_help(void)
{
	printf_P(PSTR("\n\rAVR488 interface (V%s " __DATE__ " " __TIME__ ")\n\r"), MY_VERSION);
	printf_P(PSTR("https://pchernikhowsky.github.io/AVR488/\n\n\r"));
	printf_P(PSTR("Available commands (all are preceded by \"++\" and not case sensitive):\n\r"));
	printf_P(PSTR("addr 1-30      Tell controller which instrument to address.\n\r"));
	printf_P(PSTR("addr           Query currently configured instrument address.\n\r"));
	printf_P(PSTR("auto 0|1       Enable (1) or disable (0) read after write.\n\r"));
	printf_P(PSTR("auto           Query read after write setting.\n\r"));
	printf_P(PSTR("clr            Issue device clear.\n\r"));
	printf_P(PSTR("debug N        Set level for debugging messages.\n\r"));
	printf_P(PSTR("debug          Query current debug level.\n\r"));
	printf_P(PSTR("default        Emulates the Arduino AR488 command.\n\r"));
	printf_P(PSTR("echo 0|1       Enable (1) or disable (0) echoing of characters received from USB port.\n\r"));
	printf_P(PSTR("echo           Query current echo setting.\n\r"));
	printf_P(PSTR("eoi 0|1        Enable (1) or disable (0) EOI with last byte.\n\r"));
	printf_P(PSTR("eoi            Query current EOI setting.\n\r"));
	printf_P(PSTR("eos 0|1|2|3    EOS terminator — 0:CR+LF, 1:CR, 2:LF, 3:None.\n\r"));
	printf_P(PSTR("eos            Query current EOS setting.\n\r"));
	printf_P(PSTR("eot_char N     End of transmission character ASCII code.\n\r"));
	printf_P(PSTR("eot_char       Query current end of transmission character ASCII code.\n\r"));
	printf_P(PSTR("eot_enable N   End of transmission character enable (1) or disable (0).\n\r"));
	printf_P(PSTR("eot_enable     Query current end of transmission character setting.\n\r"));
	printf_P(PSTR("help           Print help about commands.\n\r"));
	printf_P(PSTR("ifc            Issue interface clear.\n\r"));
	printf_P(PSTR("llo            Disable front panel operation of the currently addressed instrument.\n\r"));
	printf_P(PSTR("loc            Enable front panel operation of the currently addressed instrument.\n\r"));
	printf_P(PSTR("mode 1         Compatibility only command - we are always a controller.\n\r"));
	printf_P(PSTR("read           Read from instrument until timeout.\n\r"));
	printf_P(PSTR("read eoi       Read from instrument until EOI detected or timeout.\n\r"));
	printf_P(PSTR("read_tmo_ms N  Timeout value, in milliseconds, for read and spoll commands.\n\r"));
	printf_P(PSTR("read_tmo_ms    Query current timeout value.\n\r"));
	printf_P(PSTR("rst            Performs power-on reset of the controller.\n\r"));
	printf_P(PSTR("savecfg 1      Save current configuration to EEPROM.\n\r"));
	printf_P(PSTR("spoll [N]      Read status byte by serial polling the instrument.\n\r"));
	printf_P(PSTR("srq            Query status of SRQ line. 0: Not asserted, 1:Asserted.\n\r"));
	printf_P(PSTR("trg [N]        Issue device trigger (GET) to the instrument.\n\r"));
	printf_P(PSTR("ver            Query AVR488 interface version.\n\r"));
	printf_P(PSTR("xdiag          Show current state of AVR IO pins.\n\r"));
}
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

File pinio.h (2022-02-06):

/*
 * pinio.h
 *
 * Created: 30-Dec-2021 3:54:58 PM
 *  
 */


#ifndef PINIO_H_
#define PINIO_H_

// ATmega168/328 -> GPIB pin mapping (using the MCP2221A)
//
//                       +-----------\_/-----------+
//        /RESET        -|1  PC6             PC5 28|-        GPIB 11: ATN
// MCP2221 6: TX        -|2  PD0             PC4 27|-        GPIB 10: SRQ
// MCP2221 5: RX        -|3  PD1             PC3 26|-        GPIB  9: IFC
//    STATUS LED        -|4  PD2             PC2 25|-        GPIB  8: NDAC
//  GPIB 17: REN        -|5  PD3             PC1 24|-        GPIB  7: NRFD
//   GPIB 5: EOI        -|6  PD4             PC0 23|-        GPIB  6: DAV
//                  Vcc -|7                      22|- GND
//                  GND -|8                      21|- AREF
//  GPIB 15: DIO7       -|9  PB6                 20|- AVcc
//  GPIB 16: DIO8       -|10 PB7             PB5 19|-        GPIB 14: DIO6
//     SN75161 DC       -|11 PD5             PB4 18|-        GPIB 13: DIO5
// SN75160/161 TE       -|12 PD6             PB3 17|-        GPIB  4: DIO4
//     SN75160 PE       -|13 PD7             PB2 16|-        GPIB  3: DIO3
//   GPIB 1: DIO1       -|14 PB0             PB1 15|-        GPIB  2: DIO2
//                       +-------------------------+

// AVR port to GPIB pin definitions
#define DAV  PINC0
#define NRFD PINC1
#define NDAC PINC2
#define IFC  PINC3
#define SRQ  PINC4
#define ATN  PINC5

// Use the high bit to indicate PORTD pins
#define REN (PIND3 | 0x80)
#define EOI (PIND4 | 0x80)
#define DC  (PIND5 | 0x80)
#define TE  (PIND6 | 0x80)
#define PE  (PIND7 | 0x80)
#define LED_STATUS (PIND2 | 0x80) // continuously toggled by _wdt_reset() to indicate life

// Defines for pin control using GPIB negative logic
#define ASSERT output_low
#define DEASSERT output_high
#define FLOAT output_float

// Prototypes for pin control functions
extern void output_float(uint8_t bit);
extern void output_high(uint8_t bit);
extern void output_low(uint8_t bit);
extern void toggle_output(uint8_t bit);
extern uint8_t input(uint8_t bit);

#endif /* PINIO_H_ */

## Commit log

2022-02-06 Included schematics
    [AVR488.sch]
2022-02-06 Added prototype image
2022-02-07 Renamed folder.
    [AVR488.sch]
2022-02-20 Fixed null command handling.
    [main.c]
2022-03-26 Added KiCad hardware files.
    [AVR488.FCStd, AVR488.kicad_pcb, AVR488.kicad_sch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]
2022-03-26 Update README.md
    Updated with KiCad hardware info.
2022-03-26 Added bill of materials
    [AVR488-BOM.csv]
2022-04-25 Bug fixes. Also improved Prologix and AR488 command set compatibility.
    [main.c]
2022-05-10 Added enclosure label.
